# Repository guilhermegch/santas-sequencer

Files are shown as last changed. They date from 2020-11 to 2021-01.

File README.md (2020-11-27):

# Santa's Sequencer
Project for PCB Badge challenge, organized by the Brazilian Computer Engineer and Youtuber Julia (@juliallabs), from the channel "Laboratório da Julia"(Julia's Lab).




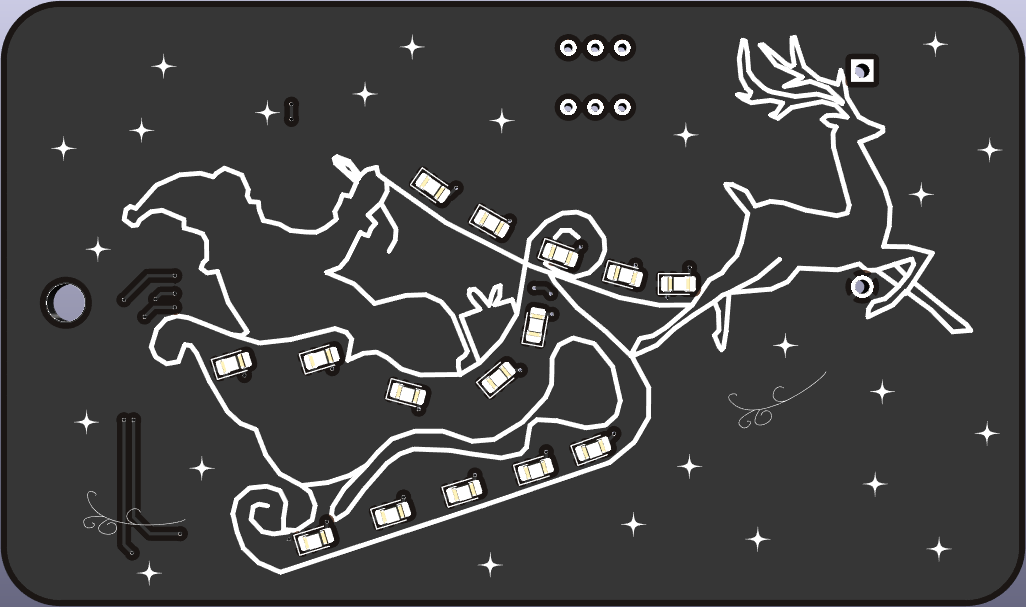
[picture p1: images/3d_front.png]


My project idea is to make a simple ornament. Its implementation is made with a Johnson decade counter IC, the CD4017, to create a sequencer. The clock circuitry was made by transistors, creating an Astable Multivibrator.

To a more complete info about the design, circuit calculations and how it works, check the documentation pdf file.

On images folder, there's the original .svg draws and the .dxf files, accepted by the Kicad software.

This hardware was developed using Kicad 5.1.8 for Linux.
This hardware is free to use, change, and distribute.

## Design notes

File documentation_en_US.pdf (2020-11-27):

## PCB Badge Challenge

## Christmas PCB Documentation

Guilherme Gomes, 2020

## Contents

1 Initial Project | 2
2 Bill of Materials (BOM) | 2
3 Calculations and how it works | 2
4 Designing the PCB | 4

## 1 Initial Project

The project idea is to make a PCB Badge, a Christmas ornament. Its implementation is made with a Johnson decade counter IC, the CD4017, to create a sequencer. The clock circuitry was made by transistors, creating an Astable Multivibrator.

## 2 Bill of Materials (BOM)

Suggestion: buy the components first and check the project for the right footprints.

Reference | Quantity | Value | Package
BT1 | 1 | CR2016/CR2025/CR2032 | Coin cell
BT | 1 | Battery Holder | -
C1 | 1 | 10uF | Electrolytic SMD
C2 | 1 | 47uF | Electrolytic SMD
D1 - D10 | 10 | Red LED | SMD 0805
D11 - D15 | 5 | White LED | SMD 0805
Q1, Q2 | 2 | BC847 | SOT-23
R1, R4 | 2 | 330R | SMD 0805
R2 | 1 | 47k | SMD 0805
R3 | 1 | 22k | SMD 0805
R5 - R19 | 15 | 100R | SMD 0805
SW1 | 1 | DPDT Switch | 8x8mm toggle switch
U1 | 1 | CD4017 | SO-16

## 3 Calculations and how it works

The CD4017 IC needs a clock pulse to increment the counter, which was generated by the Astable Multivibrator. This circuit was chosen rather than other simple oscillators like the 555 IC or CD4093 IC, because of the possibility of choosing the hold time of the clock pulse without using a microcontroller.

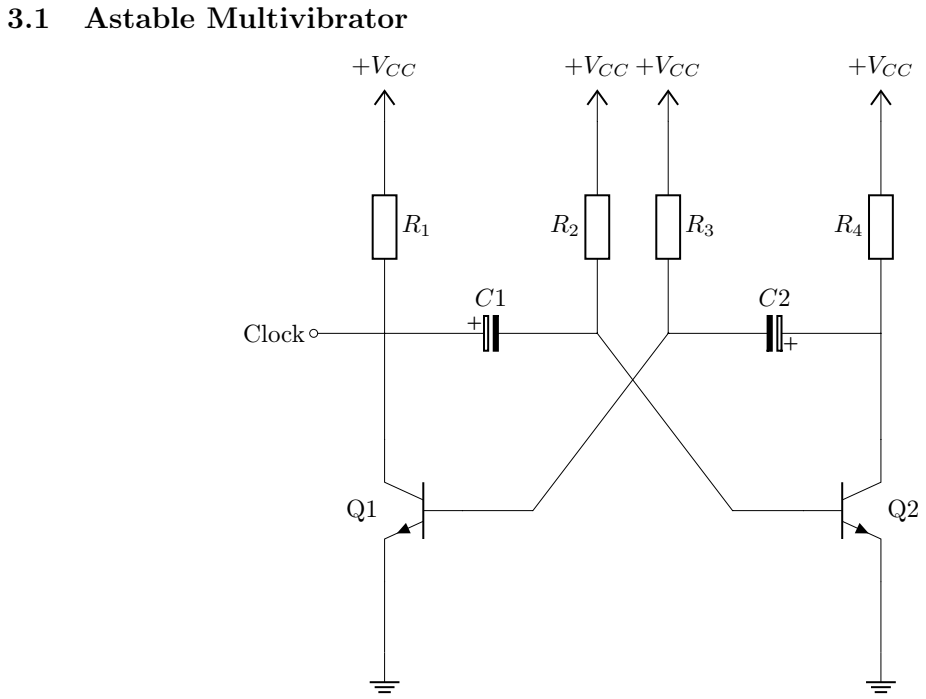
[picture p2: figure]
3.1 Astable Multivibrator; +VCC; Clock

The conduction time of each transistor is controller by the value of the capacitors and resistors. The equation to calculate this is given by
tc = 0, 69 · R · C where R is the resistance in ohms (Ω) and F is the capacitance in Farads (F). The components that controls the transistors are R2, R3, C1 and C2. The control is made in a cross-way, with means that the combination of R2 and C1 controls the timeout of the circuit, since they are connected to the base of Q2, while R3 and C2 controls the clock pulse, controlling the polarization of Q1. R1 e R4 are resistors to control the current flow of transistor. To the PCB, the following values were used:

R1 e R4 = 330Ω
R2 = 47kΩ
R3 = 22kΩ
C1 = 10µF
C2 = 47µF

Doing the math, we have:

ttimout = 0, 69 · 47 × 10³

- 10 × 10⁻⁶ = 0, 3243 = 324, 3ms

tclock = 0, 69 · 22 × 10³

- 47 × 10⁻⁶ = 0, 71346 = 713, 46ms

This clock pulse is sent to the counter.

### 3.2 Sequential circuitry

Every rising edge of the clock pulse increments the 4017 output. When turned on, the Q0 output is set to a high logic level, while the others are set to low. At the first clock pulse, Q0 is set to low, and Q1 goes to high. And that continues at every clock pulse, as described on the component datasheet:

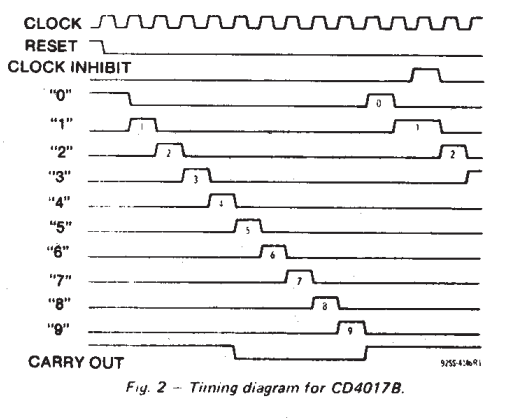
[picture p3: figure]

The LEDs are connected to the counter output. In the final circuit, every red LED shown in the picture below are two red LEDs in parallel.

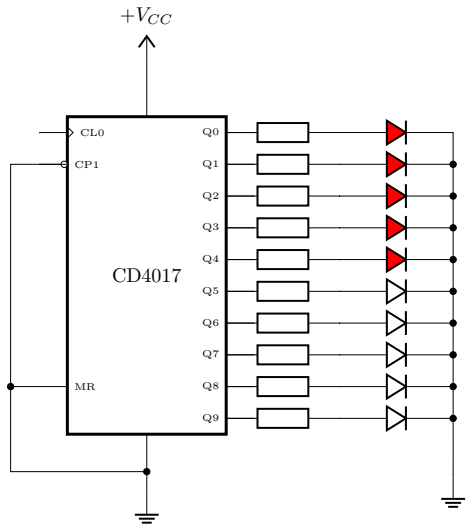
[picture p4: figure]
+VCC

## 4 Designing the PCB

To make the board, the chosen option is SMD components with 0805 package, to keep the circuit small, yet with a comfortable size to be hand-soldered. The initial design was made using Inkscape, to draw .svg files, that are exported as a .dxf file, natively recognized by the Kicad software.

### 4.1 Initial design

After the ideas, given the size limits (100 x 100 mm), the design below was considered to be the board edge, with the following design to be made on the silk screen layer.

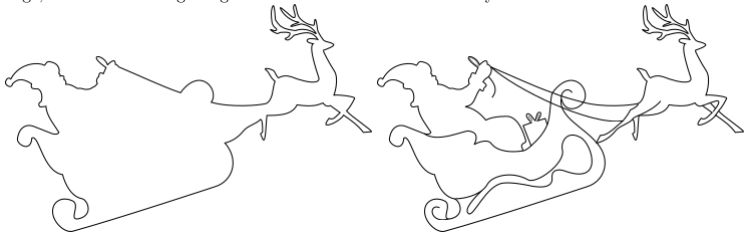
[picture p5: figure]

While trying to design the PCB, the size has proven to be too small, and the board edge design was changed to be a Christmas tree ornament, or to be used as a backpack tag, with a new size of about 95 x 55 mm.

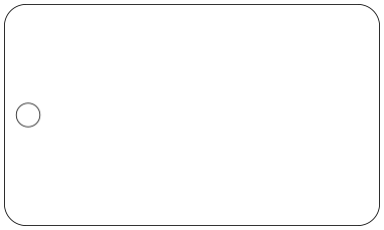
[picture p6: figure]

### 4.2 Final design and layers

Since the intention is to be a pretty circuit, it was filled with more ornaments, like the stars and the snow to give movement to the Santa and his sleigh. To keep the board front layer as clean as possible, all routing was made on the backside, with the front copper layer only getting small jumper trails. The solder mask will be black, to represent the night sky, while the Santa figure and the stars are on the pad layer, to receive a shining silver finish. The snow is at the silk screen layer, since it going to be white, and contrasts with the black background. The hole on the board was made with a bigger via, with 3.8 mm of diameter with a 3.5 mm hole. Via is the choice instead of a simple board edge cut because of the internal copper finish that the via receives.
After all the changes, this is a 3D visualization of the board:

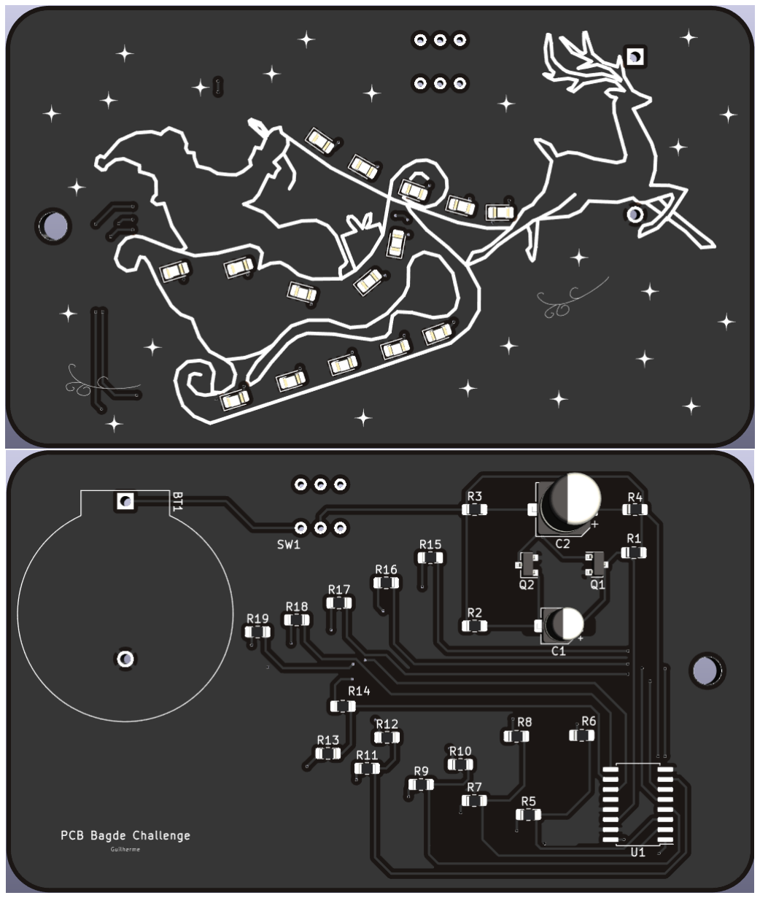
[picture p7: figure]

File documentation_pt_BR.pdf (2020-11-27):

## PCB Badge Challenge

## Documentação da PCB de Natal

Guilherme Gomes, 2020

## Sumário

1 Projeto Inicial | 2
2 Lista de materiais | 2
3 Funcionamento do circuito e cáculos | 2
4 Fazendo a PCB | 4

## 1 Projeto Inicial

A ideia do projeto é fazer uma badge de PCB, um enfeite com tema natalino. Foi implementado um circuito com o CI contador de década CD4017, para criar um sequencial. O circuito de clock foi feito usando um multivibrador astável com dois transistores.

## 2 Lista de materiais

Sugestão: adquira os componentes na sua loja de preferência e confira se os footprints estão corretos.

Referência | Quantidade | Valor | Encapsulamento | Link para compra
BT1 | 1 | CR2016/CR2025/CR2032 | Bateria Moeda | Proesi CR2025 (https://proesi.com.br/bateria-pilha-cr2025-3v-190mah-20x2-5mm.html)
BT | 1 | Suporte bateria | - | Proesi (https://proesi.com.br/suporte-para-bateria-cr-2016-2025-2032.html)
C1 | 1 | 10uF | SMD Eletrolítico | Proesi 10uF/25V (https://proesi.com.br/capacitor-eletrolitico-10uf-25v-smd.html)
C2 | 1 | 47uF | SMD Eletrolítico | Proesi 47uF/10V (https://proesi.com.br/capacitor-eletrolitico-47uf-10v-smd.html)
D1 - D10 | 10 | Vermelho | Led SMD 0805 | Proesi (https://proesi.com.br/led-smd-0805-vermelho.html)
D11 - D15 | 5 | Branco | Led SMD 0805 | Proesi (https://proesi.com.br/led-smd-0805-branco.html)
Q1, Q2 | 2 | BC847 | BJT: SOT-23 | Proesi (https://proesi.com.br/smd-bc847-transistor.html)
R1, R4 | 2 | 330R | SMD 0805 | Proesi (https://proesi.com.br/resistor-smd-0805-5-330r.html)
R2 | 1 | 47k | SMD 0805 | Proesi (https://proesi.com.br/resistor-smd-0805-5-47k.html)
R3 | 1 | 22k | SMD 0805 | Proesi (https://proesi.com.br/resistor-smd-0805-5-22k.html)
R5 - R19 | 15 | 100R | SMD 0805 | Proesi (https://proesi.com.br/resistor-smd-0805-5-100r.html)
SW1 | 1 | Chave DPDT | DPDT 6 terminais | Proesi - Chave 8x8 com trava (https://proesi.com.br/chace-gancho-8x8-a-com-trava-6-terminais-2-contatos-na-nf.html)
U1 | 1 | CD4017 | SO-16 | Proesi (https://proesi.com.br/smd-cd4017-circuito-integrado.html)

## 3 Funcionamento do circuito e cáculos

Para o seu funcionamento, o CI contador CD4017, necessita de um pulso de clock, que foi obtido através de um circuito conhecido como Multivibrador Astável. Esse circuito foi selecionado em detrimento a outras opções (como osciladores simples baseados no CI 555 ou no CI 4093), devido a possibilidade de controle do tempo de espera do pulso de clock. Foram escolhidos componentes discretos pelo desafio e relativa simplicidade, pois não queria utilizar circuitos microcontroladores.

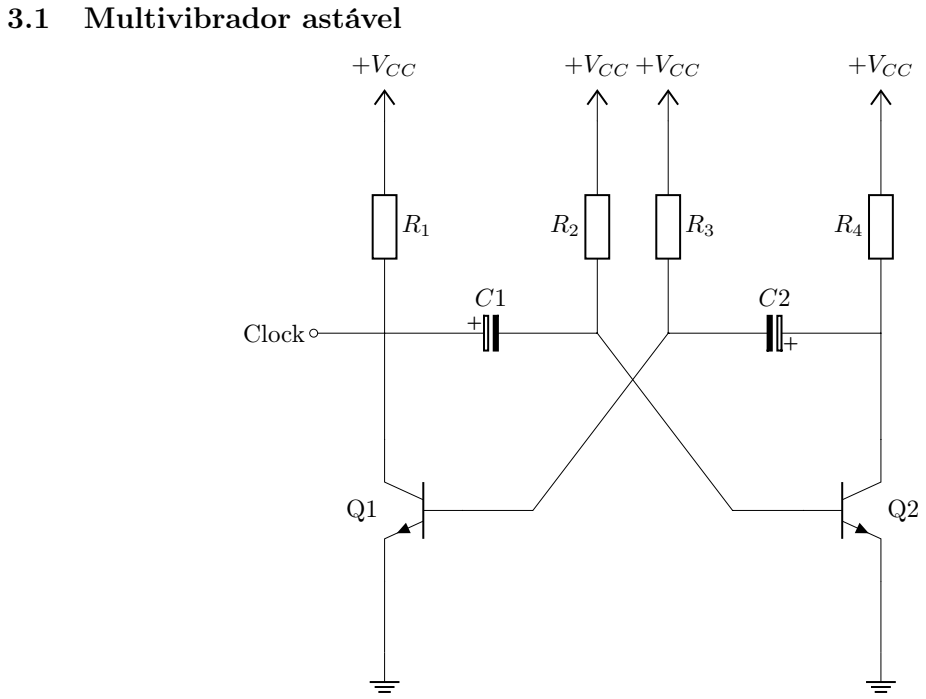
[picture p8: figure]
3.1 Multivibrador astável; +VCC; Clock

O tempo de condução de cada transistor, é alterado segundo os valores dos capacitores e dos resistores. A equação que permite que isso seja calculado é dada por

tc = 0, 69 · R · C

onde R é o valor do resistor em ohms (Ω) e F é o valor do capacitor eletrolítico em Farads (F). Os componentes que controlam os transistores são R2, R3, C1 e C2. Lembrando que o controle é feito de maneira cruzada, ou seja, a combinação de R2 e C1 controlam o tempo de espera do circuito,pois estão na base de Q2, enquanto R3 e C2 controlam o pulso de clock, controlando a polarização da base do transistor Q1. Os resistores R1 e R4 são resistores para polarizar o transistor e garantir o funcionamento do circuito. Para a PCB, foram escolhidos os seguintes valores:

R1 e R4 = 330Ω
R2 = 47kΩ
R3 = 22kΩ
C1 = 10µF
C2 = 47µF

Fazendo os cálculos temos que:

tespera = 0, 69 · 47 × 10³

- 10 × 10⁻⁶ = 0, 3243 = 324, 3ms

tclock = 0, 69 · 22 × 10³

- 47 × 10⁻⁶ = 0, 71346 = 713, 46ms

Esse pulso de clock é enviado para o contador CD4017.

### 3.2 Circuito sequencial

A cada borda de subida do pulso de clock, o 4017 incrementa uma saída. Ao ser energizado, a saída Q0 é colocada em nível alto, enquanto as outras ficam em nível baixo. Ao receber o primeiro pulso de clock, a saída Q1 vai para nível alto e o restante para nível baixo, e assim sucessivamente, comportamento descrito no datasheet do componente:


Os leds são conectados nas saídas do contador. Na realidade, foram ligados dois leds vermelhos em paralelo para cada led vermelho representado no diagrama a seguir:

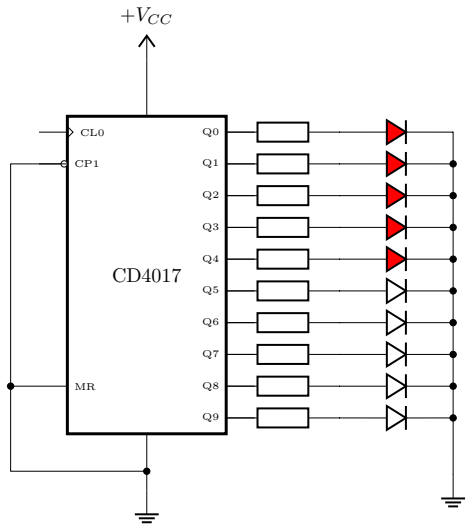
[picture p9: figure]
+VCC

## 4 Fazendo a PCB

Foram escolhidos para a confecção da placa componentes SMD com encapsulamento 0805, para manter o circuito pequeno, mas com componentes com um tamanho que seja confortável para a soldagem a mão. O design da placa foi feito usando o software Inkscape, para desenhar arquivos com a extensão .svg, que foram posteriormente convertidos em arquivos .dxf, que são nativamente reconhecidos pelo software KiCad.

### 4.1 Design inicial

Após definidas as ideias, dadas as limitações de tamanho (100 x 100 mm), o design abaixo foi considerado para ser o formato da borda da placa, com o design a ser feito na cama de silk screen.

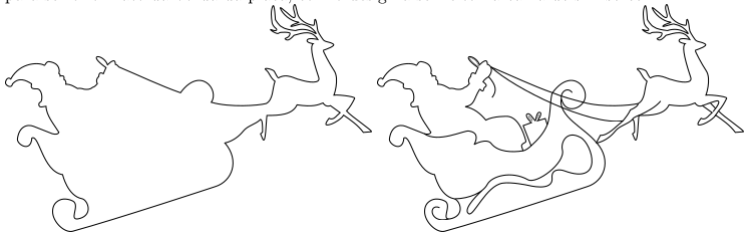
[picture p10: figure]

Durante a tentativa de design de PCB, o tamanho se mostrou limitante, e a placa foi convertida em um design para ser um enfeite pendurável em árvore, ou até mesmo em uma mochila ou similar, com o novo tamanho de 95 x 55 mm.

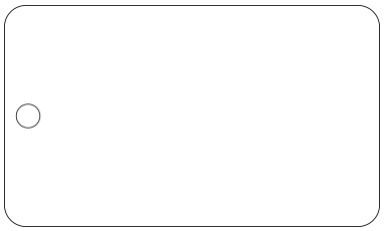
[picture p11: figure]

### 4.2 Design final e camadas

Como o intuito é fazer um circuito que além de funcional, seja bonito, foram acrescentados alguns ornamentos, como estrelas e riscos de neve para representar o movimento do trenó. Então ficou decidido que a frente da placa seria a mais limpo possível, com trilhas pequenas e discretas. A solder mask será da cor preta, para representar o céu noturno, enquanto a figura do papai noel e as estrelas estão na camada dos pads, para receberem um acabamento metálico prateado. Os riscos de neve ficaram na camada de silk screen para dar um contraste com o fundo preto. O furo de fixação foi feito através de uma via de maior diâmetro, com 3,8 mm de diâmetro e 3,5 mm de furo.
Foram então acrescentados ornamentos na placa e algumas mudanças foram feitas, sendo essa a visualização 3D do design final.


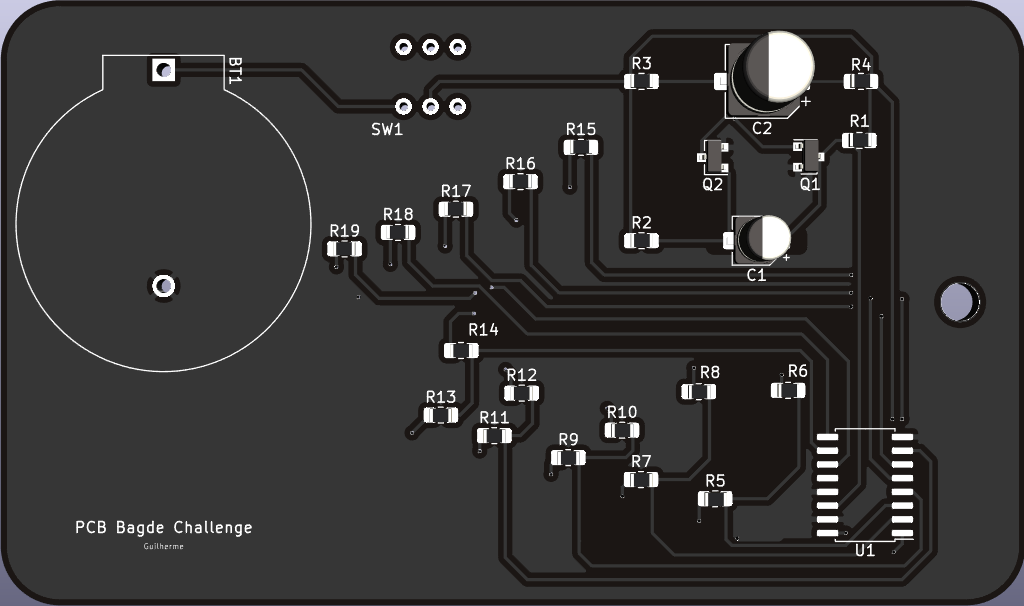
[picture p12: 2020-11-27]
images/3d_back.png

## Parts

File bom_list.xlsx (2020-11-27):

BOM LIST SANTA’S SEQUENCER
DESCRIPTION | QUANTITY | POSITION | PART NUMBER
COIN CELL BATTERY HOLDER 2025 | 1 | PW1 | BAT-HLD-001
ELECTROLYTIC CAPACITOR 10uF | 1 | C1 | 865090240001, can be replaced to similar
ELECTROLYTIC CAPACITOR 47uF | 1 | C2 | 865080242004, can be replaced to similar
LED 0805 RED | 10 | D1 – D10 | LTST-C171KRKT, can be replaced to similar
LED 0805 WHITE | 5 | D11 – D15 | LTW-170TK, can be replaced to similar
TRANSISTOR BC847 | 2 | Q1, Q2 | BC847, can be replaced to similar
RESISTOR 47k 0805 | 1 | R2 | CRGCQ0805J47K, can be replaced to similar
RESISTOR 22k 0805 | 1 | R3 | CRGS0805J22K, can be replaced to similar
RESISTOR 330R 0805 | 2 | R1, R4 | CRGS0805J330R, can be replaced to similar
RESISTOR 100R 0805 | 15 | R5 – R19 | CRGS0805J100R, can be replaced to similar
PUSH-PUSH DPDT SWITCH | 1 | SW1 | TL2285EE, can be replaced to similar
DECADE COUNTER 4017 | 1 | U1 | HEF4017BT,653, can be replaced to similar

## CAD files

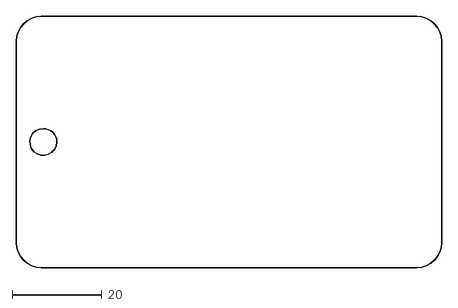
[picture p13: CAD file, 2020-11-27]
images/board_edge.dxf
94.8 x 56.0

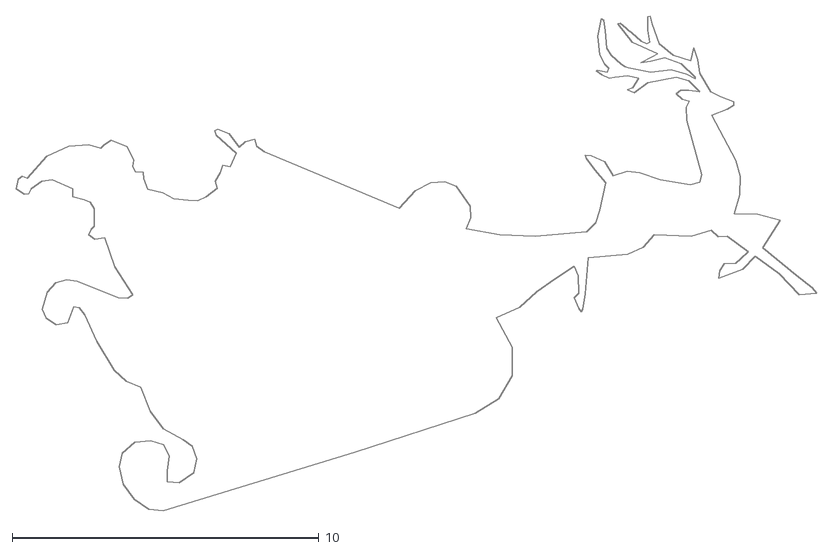
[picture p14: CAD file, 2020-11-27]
images/edge.dxf
26.1 x 16.1

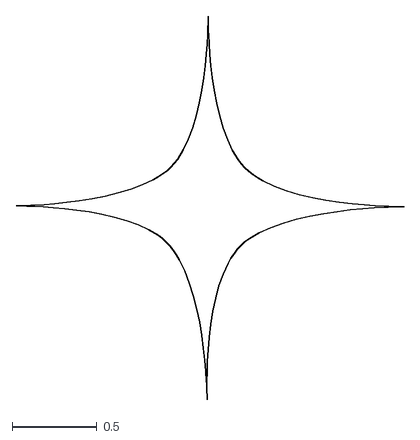
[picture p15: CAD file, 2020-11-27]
images/estrela.dxf
2.29 x 2.26

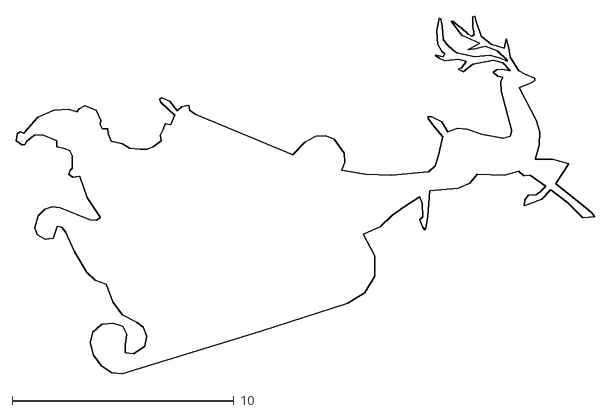
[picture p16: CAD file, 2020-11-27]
images/edge_after.dxf
26.1 x 16.1

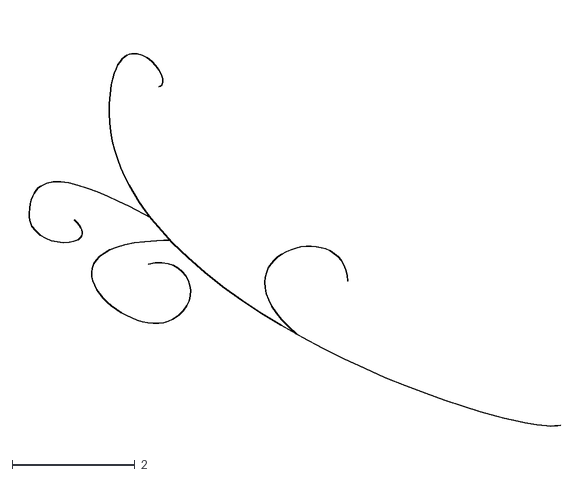
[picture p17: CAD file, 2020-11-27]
images/neve.dxf
8.87 x 6.88

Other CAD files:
images/top_silk.dxf

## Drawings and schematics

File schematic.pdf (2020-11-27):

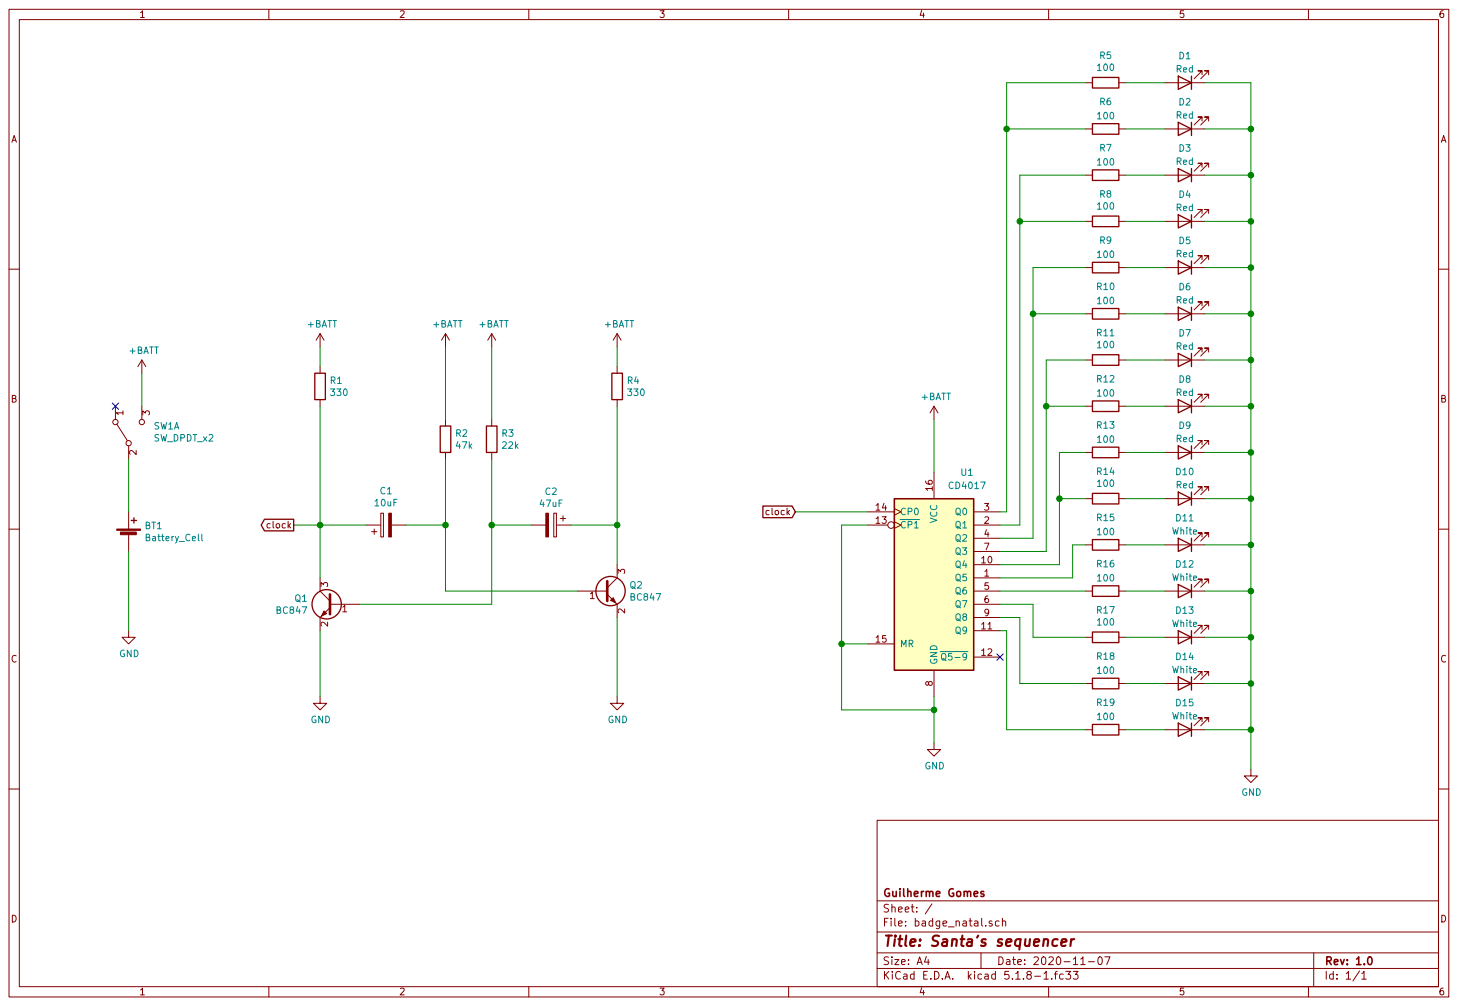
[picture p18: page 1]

Id: 1/1 Title: Santa's sequencer

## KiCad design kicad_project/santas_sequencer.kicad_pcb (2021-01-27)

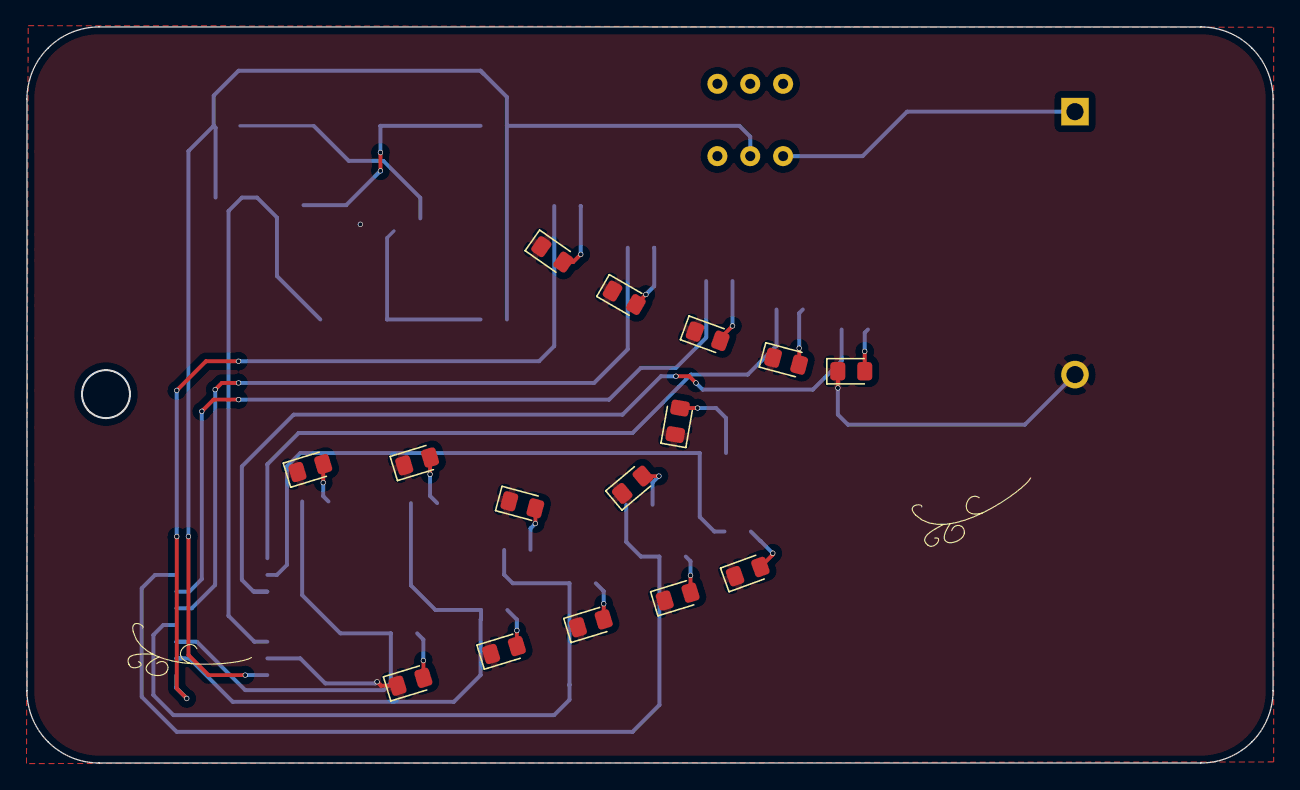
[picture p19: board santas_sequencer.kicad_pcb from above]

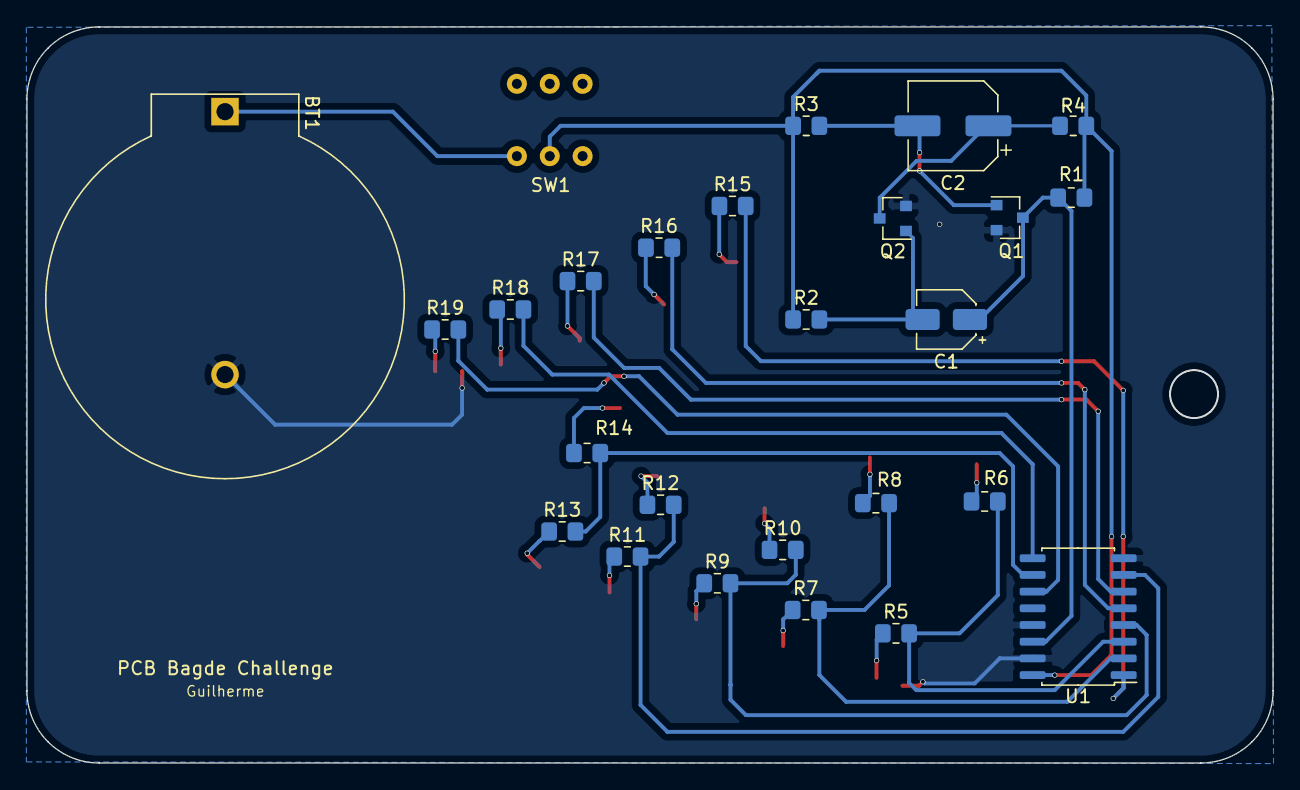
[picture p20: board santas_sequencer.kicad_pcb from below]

Board: 2 copper layers, 94.8 x 56.0 mm, 41 parts (26 on the bottom side), 32 nets.

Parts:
BT1: Battery_Cell; BatteryHolder_ComfortableElectronic_CH273-2450_1x2450
C1: 10uF; CP_Elec_4x5.8
C2: 47uF; CP_Elec_6.3x7.7
D1, D2, D3, D4, D5, D6, D7, D8, D9, D10: Red; LED_0805_2012Metric_Pad1.15x1.40mm_HandSolder
D11, D12, D13, D14, D15: White; LED_0805_2012Metric_Pad1.15x1.40mm_HandSolder
Q1, Q2: BC847; SOT-23
R1, R4: 330; R_0805_2012Metric_Pad1.20x1.40mm_HandSolder
R2: 47k; R_0805_2012Metric_Pad1.20x1.40mm_HandSolder
R3: 22k; R_0805_2012Metric_Pad1.20x1.40mm_HandSolder
R5, R6, R7, R8, R9, R10, R11, R12, R13, R14, R15, R16, R17, R18, R19: 100; R_0805_2012Metric_Pad1.20x1.40mm_HandSolder
SW1: SW_DPDT_x2; DPDT_Switch_6_terminals
U1: CD4017; SO-16_5.3x10.2mm_P1.27mm

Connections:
+BATT: R1.1, R2.1, R3.1, R4.1, SW1.3, U1.16
GND: BT1.2, D1.1, D2.1, D3.1, D4.1, D5.1, D6.1, D7.1, D8.1, D9.1, D10.1, D11.1, D12.1, D13.1, D14.1, D15.1, Q1.2, Q2.2, U1.8, U1.13, U1.15
unnamed: BT1.1, SW1.2
unnamed: C1.2, Q2.1, R2.2
unnamed: C2.1, Q2.3, R4.2
unnamed: C2.2, Q1.1, R3.2
unnamed: D1.2, R5.1
unnamed: D2.2, R6.1
unnamed: D3.2, R7.1
unnamed: D4.2, R8.1
unnamed: D5.2, R9.1
unnamed: D6.2, R10.1
unnamed: D7.2, R11.1
unnamed: D8.2, R12.1
unnamed: D9.2, R13.1
unnamed: D10.2, R14.1
unnamed: D11.2, R15.1
unnamed: D12.2, R16.1
unnamed: D13.2, R17.1
unnamed: D14.2, R18.1
unnamed: D15.2, R19.1
unnamed: R5.2, R6.2, U1.3
unnamed: R7.2, R8.2, U1.2
unnamed: R9.2, R10.2, U1.4
unnamed: R11.2, R12.2, U1.7
unnamed: R13.2, R14.2, U1.10
unnamed: R15.2, U1.1
unnamed: R16.2, U1.5
unnamed: R17.2, U1.6
unnamed: R18.2, U1.9
unnamed: R19.2, U1.11
clock: C1.1, Q1.3, R1.2, U1.14

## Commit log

2020-11-27 Add files via upload
    gerber files
    [badge_natal-B_Cu.gbr, badge_natal-B_Mask.gbr, badge_natal-B_Paste.gbr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]
2020-11-27 project images
    [board_edge.dxf, edge.dxf, edge_after.dxf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]
2020-11-27 kicad project files
    [santas_sequencer.kicad_pcb, santas_sequencer.sch]
2020-11-27 BOM list
    [bom_list.xlsx]
2020-11-27 project schematic
2020-11-27 Removing gerber zip
2020-11-27 gerber zip file
2021-01-27 Updating the pcb to correct a project flaw: the transistors ground plane was isolated from other grounds
    [santas_sequencer-B_Cu.gbr, santas_sequencer-B_Mask.gbr, santas_sequencer-B_Paste.gbr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]
